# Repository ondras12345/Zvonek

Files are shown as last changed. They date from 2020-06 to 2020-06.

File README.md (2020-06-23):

# Zvonek
A simple circuit for ringing a doorbell by briefly pressing a light switch.

The PCB was designed in EAGLE. It was milled out using a CNC. Because I needed
the PCB to be as small as possible, I had to place some of the components
outside the 1.27mm grid.

A fuse (not shown in the schematic) should be placed in series with the 12V
power line.

## Operation
The circuit is connected to a regular light switch, so that the neon lamp is
lit when the light is lit. The neon lamp is pointed at a LDR, thus forming
an optocoupler. A piece of heatshrink tubing is put over this assembly to
isolate it from ambient light.

The circuit is powered from the 12V DC bell power supply and is isolated from
the mains.

When the light is lit, a timer (about 2 s) starts. If the timer has not
finished yet and the light is already switched off, a MOSFET turns on and
the bell sounds.

```
       1   +-----------+           +---+
switch     |           |           |   |
       0 --+           +-----------+   +-------

       1   +------+                +------+
timer      |      |                |      |
       0 --+      +----------------+      +----

       1                               +---+
bell                                   |   |
       0 ------------------------------+   +---
```

This circuit should not be used with regular light bulbs, because the brief
switch-ons would reduce their lifespan. An LED light should be used instead.

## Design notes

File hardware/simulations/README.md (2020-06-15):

# Simulations
These simulations were created using
http://www.falstad.com/circuit/circuitjs.html .

**WARNING**: These simulations may not match the final circuit.

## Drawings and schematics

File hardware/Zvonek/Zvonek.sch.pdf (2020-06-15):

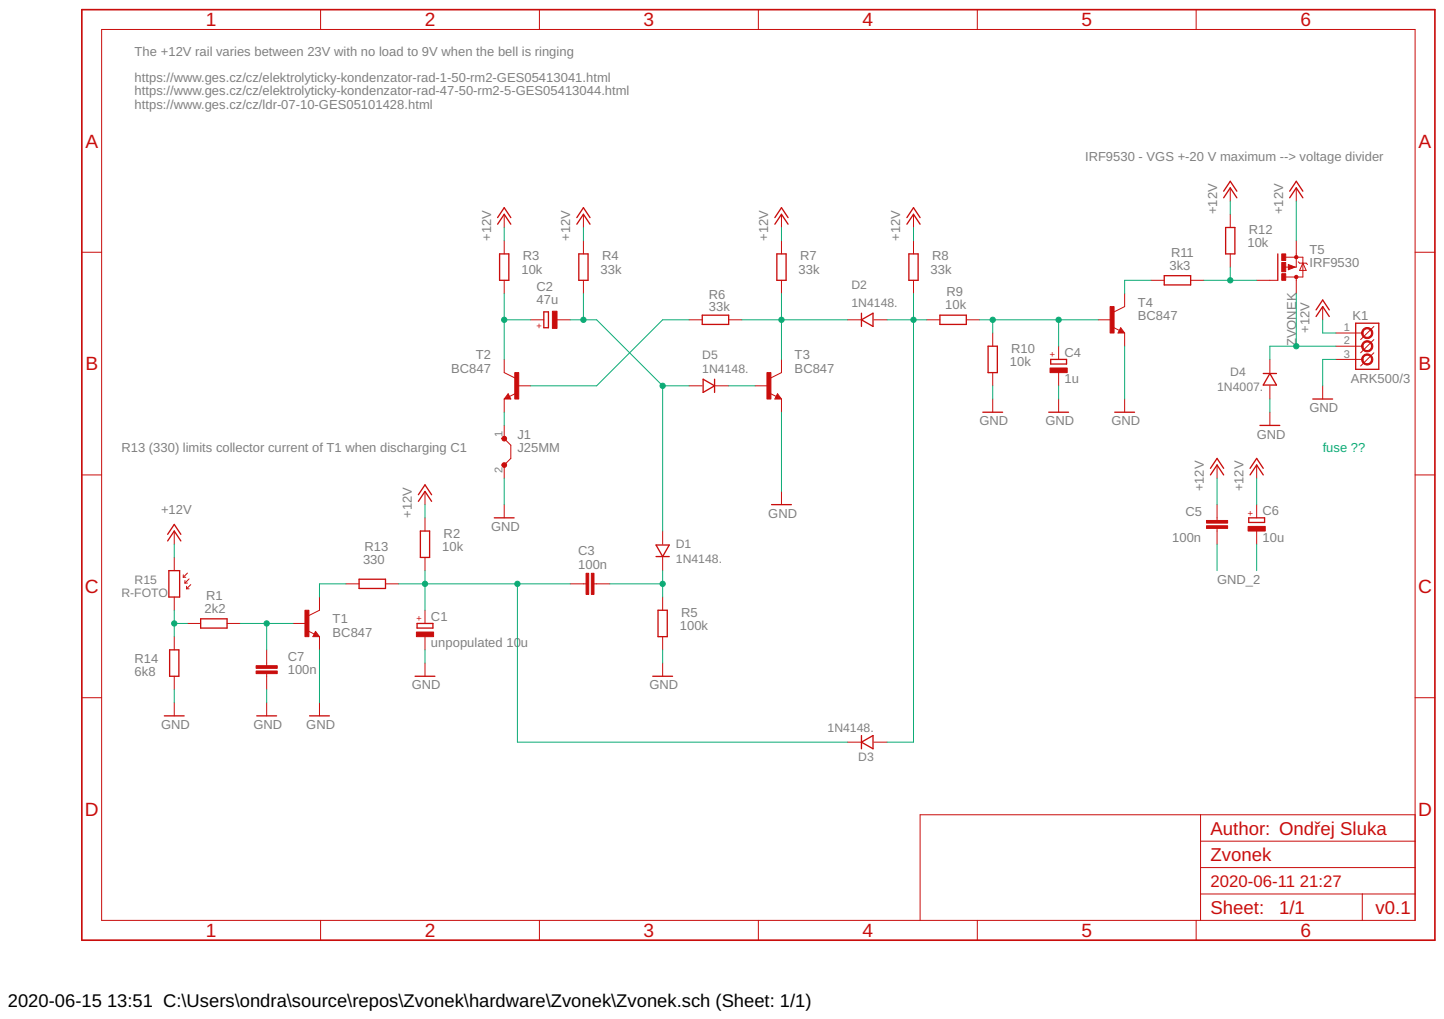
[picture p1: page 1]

The +12V rail varies between 23V with no load to 9V when the bell is ringing

https://www.ges.cz/cz/elektrolyticky-kondenzator-rad-1-50-rm2-GES05413041.html
https://www.ges.cz/cz/elektrolyticky-kondenzator-rad-47-50-rm2-5-GES05413044.html
https://www.ges.cz/cz/ldr-07-10-GES05101428.html

IRF9530 - VGS +-20 V maximum --> voltage divider

R13 (330) limits collector current of T1 when discharging C1

2020-06-15 13:51 C:\Users\ondra\source\repos\Zvonek\hardware\Zvonek\Zvonek.sch (Sheet: 1/1)

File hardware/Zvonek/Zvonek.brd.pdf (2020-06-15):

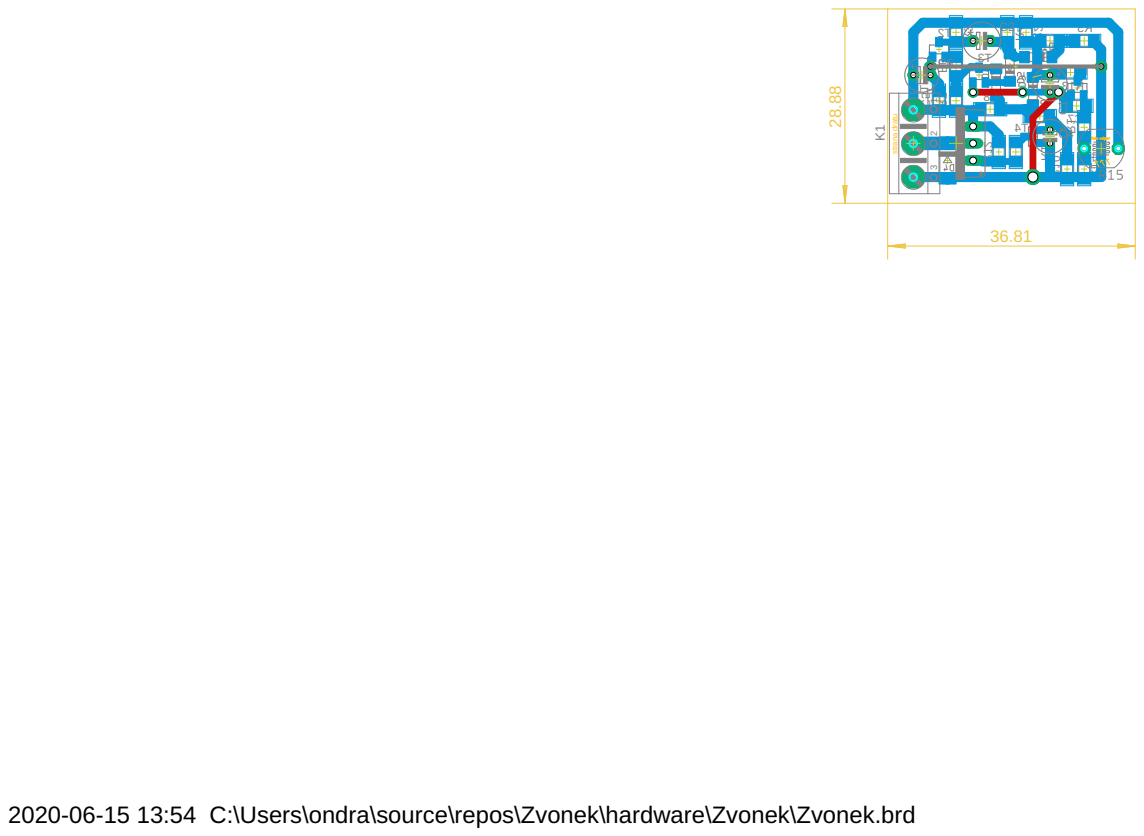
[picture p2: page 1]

2020-06-15 13:54 C:\Users\ondra\source\repos\Zvonek\hardware\Zvonek\Zvonek.brd

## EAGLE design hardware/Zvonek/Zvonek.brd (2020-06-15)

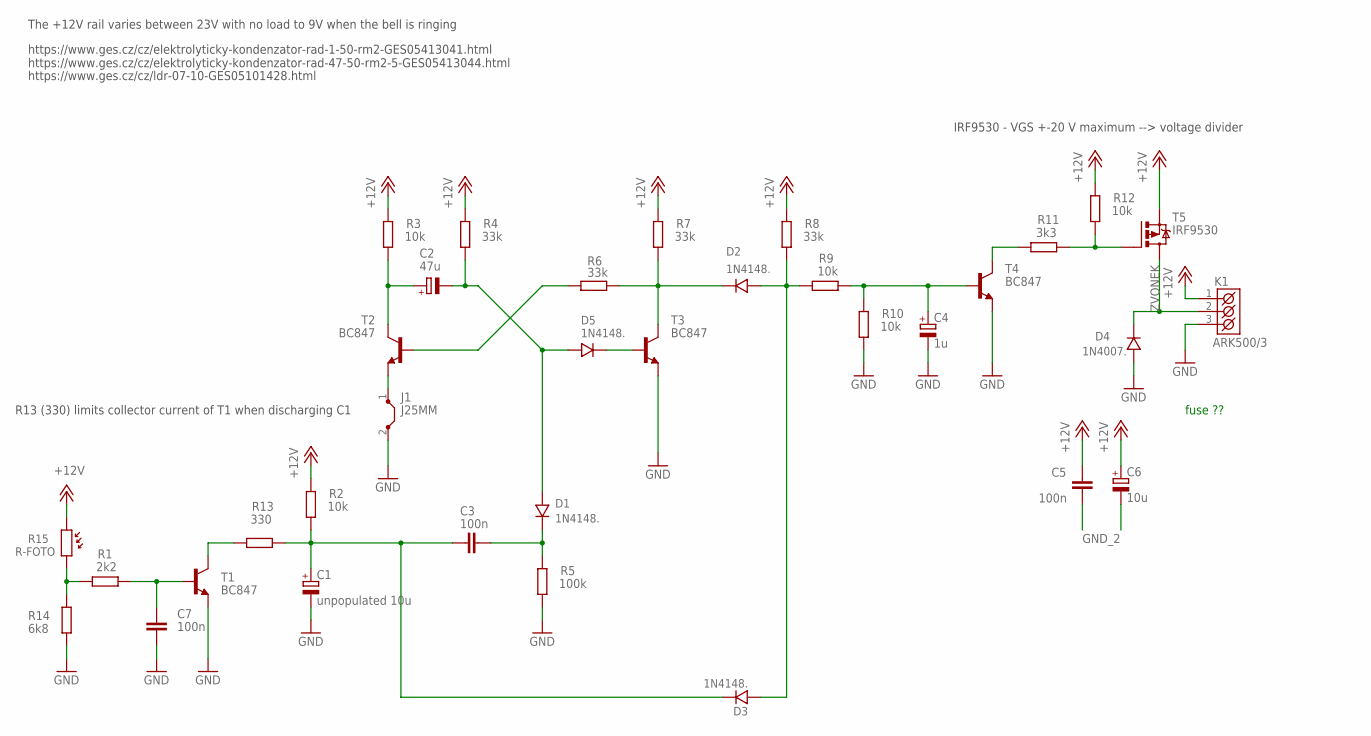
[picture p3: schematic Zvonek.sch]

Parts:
C1: unpopulated 10u; E2,5-5
C2: 47u; E2,5-6
C3, C5, C7: 100n; C1206
C4: 1u; E2-5
C6: 10u; E2,5-5
D1, D2, D3, D5: 1N4148.; SOD-80
D4: 1N4007.; SM-1
J1: J25MM; 25
K1: ARK500/3
R1: 2k2; R1206
R2, R3, R9, R10, R12: 10k; R1206
R4, R6, R7, R8: 33k; R1206
R5: 100k; R1206
R11: 3k3; R1206
R13: 330; R1206
R14: 6k8; R1206
R15: R-FOTO
T1, T2, T3, T4: BC847; SOT23
T5: IRF9530; TO220BV

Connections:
+12V: C5.2, C6.+, K1.1 (K1), R2.2, R3.2, R4.2, R7.2, R8.2, R12.2, R15.1, T5.S
GND: C1.-, C4.-, C7.1, D4.A, J1.2, K1.3 (K3), R5.1, R10.1, R14.2, T1.2 (E), T3.2 (E), T4.2 (E)
GND_2: C5.1, C6.-, J1.1, T2.2 (E)
unnamed: D2.K, R6.2, R7.1, T3.3 (C)
unnamed: R6.1, T2.1 (B)
unnamed: C2.-, D1.A, D5.A, R4.1
unnamed: C2.+, R3.1, T2.3 (C)
unnamed: D2.A, D3.A, R8.1, R9.2
unnamed: C3.2, D1.K, R5.2
unnamed: R13.2, T1.3 (C)
unnamed: C7.2, R1.1, T1.1 (B)
unnamed: C4.+, R9.1, R10.2, T4.1 (B)
unnamed: R11.2, T4.3 (C)
unnamed: R11.1, R12.1, T5.G
unnamed: D5.K, T3.1 (B)
unnamed: C1.+, C3.1, D3.K, R2.1, R13.1
unnamed: R1.2, R14.1, R15.2
ZVONEK: D4.K, K1.2 (K2), T5.D

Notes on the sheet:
IRF9530 - VGS +-20 V maximum --> voltage divider
The +12V rail varies between 23V with no load to 9V when the bell is ringing
fuse ??
https://www.ges.cz/cz/elektrolyticky-kondenzator-rad-1-50-rm2-GES05413041.html https://www.ges.cz/cz/elektrolyticky-kondenzator-rad-47-50-rm2-5-GES05413044.html
R13 (330) limits collector current of T1 when discharging C1
https://www.ges.cz/cz/ldr-07-10-GES05101428.html

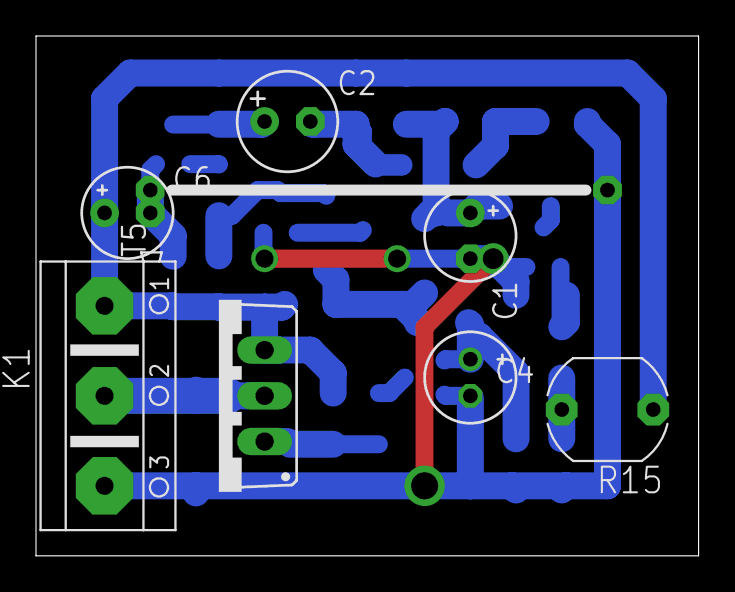
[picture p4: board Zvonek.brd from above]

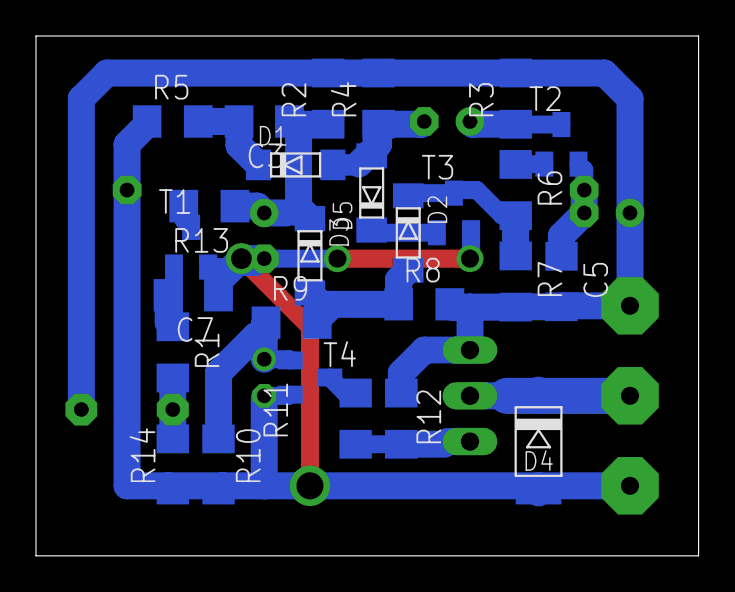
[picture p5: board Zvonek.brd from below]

Board: 2 copper layers, 36.8 x 28.9 mm, 34 parts (26 on the bottom side), 18 nets.

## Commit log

2020-06-15 Add project files
    This is the version of the PCB that was actually manufactured.
    (Copper clad only, component values may not match the final product.)
    WARNING: The simulations may not be up to date.
    [Zvonek.brd, Zvonek.sch]
2020-06-15 Change some component values
    This version matches the board that was manufactured.
    [Zvonek.brd, Zvonek.sch]

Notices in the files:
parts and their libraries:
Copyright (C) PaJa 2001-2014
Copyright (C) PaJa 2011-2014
